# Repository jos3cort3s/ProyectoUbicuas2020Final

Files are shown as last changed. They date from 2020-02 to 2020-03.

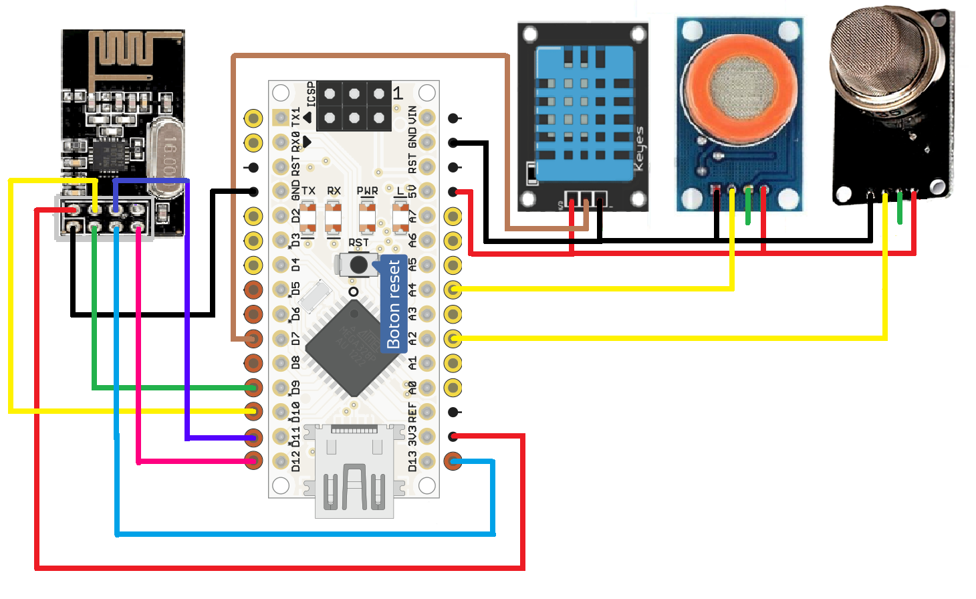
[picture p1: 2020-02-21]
ProyectoArduino/Imagenes/ConectionExternalModule.png

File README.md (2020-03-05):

# Proyecto Plataformas Ubicuas 2020

## Resumen 📋

El proyecto CoPPm es la integración de diversos sistemas informáticos y  herramientas hardware bajo costos, que permita el aprendizaje y la interacción con diversos sistemas telemáticos, sistemas IoT, además el  modelado de piezas en 3D para la creación de prototipos que permitan dar  la solución a los problemas cotidianos y den valor agregado a  proyectos educativos.
Este proyecto reúne el uso de sensores y controladores arduino, para la creación de dos módulos que permitan sensar y notificar  a los usuario que grado grado de contaminación existe en su entorno, esto permite que los usuarios puedan tomar acciones preventivas que ayuden a minimizar problemas de salud. El sistema se complementa con una App Móvil Android y un servicio en la Nube que da al usuario herramientas para el seguimiento de la calidad del aire en sus rutinas diarias y recomendaciones de sus recorridos y hábitos de manejo que minimice la interacción con puntos críticos. El sistema funciona como una red de sensores,  en donde cada usuario se comporta como nodo, brindando un mayor espectro de las condiciones reales de contaminación en una ciudad.
En las Carpetas puedes encontrar toda la documentación,  códigos, librerías, y modelos 3d que fueron utilizados en este proyecto. 

## Introducción 🚀

Se espera que hacia 2050 la población mundial pase de 7 mil millones de personas a más de 9 mil millones y se proyecta que la economía mundial crezca casi cuatro veces, con una creciente demanda de energía y de recursos naturales. Se proyecta que hacia 2050 casi 70% de la población mundial será urbana, lo que aumentará los desafíos respecto a la contaminación atmosférica, la congestión del transporte y la gestión de la basura. Bajo este escenario la contaminación del aire se convertirá en la principal causa ambiental de mortalidad prematura en el mundo, para el 2050 el número de muertes prematuras derivadas de la exposición a partículas suspendidas aumentará más del doble y alcanzará 3.6 millones cada año.
En América Latina y el Caribe (LAC por sus siglas en inglés), por lo menos 100 millones de personas están expuestas a niveles de contaminación del aire por encima de los recomendados por la Organización Mundial de la Salud (OMS) (Cifuentes, 2005). Los grupos más vulnerables a los efectos dañinos de una mala calidad del aire incluyen a niños, adultos mayores, personas con previos problemas de salud y población de bajos estratos socioeconómicos (Joanne Green, 2013). 
En Colombia un informe  realizado por el Departamento Nacional de Planeación (DNP), concluye que la contaminación del aire mata cada año en promedio a 8.000 personas mayores de 44 años, de este total, 668 están relacionadas con cáncer de pulmón y 7.362 con enfermedades cardiopulmonares, enfermedades que seguirán en aumento el los próximos años. 
En el caso de Bogotá, la Cámara de Comercio informó que la capital solo cuenta con 13 estaciones de monitoreo fijo y una móvil las cuales resultan insuficientes para registrar la calidad del aire, las cuales presentan datos parciales, que no interpretan a cabalidad las condiciones reales de contaminación en lugares puntuales de la ciudad (Getty, 2019).

### Por qué 📌
Porque tu salud y la de tus eres queridos es el mayor privilegio que puedes tener.

### Cómo ✒️
Nuestros productos brindan la posibilidad de que las personas tomen las mejores decisiones en el cuidado de su salud,  basadas en la informacion presisa y oportuna.

### Qué 📄
Ofrecemos un producto para Vehiculos y servicios en la nube que permitan el monitoreo y alerta de las condiciones de contaminates en el aire a nivel del suelo en tiempo real, seguimiento de los puntos criticos de contaminacion en el aire en tus recorridos cotidianos.

## Video 📢
Para  observar la puesta en funcionamiento del prototipo final, se a creado un vídeo en donde se visualizan los principales detalles del sistema. Cualquier observación, retroalimentación o duda la puedes dejar en los comentarios del vídeo, si te fue de utilidad déjanos tu like.

https://www.youtube.com/watch?v=Scrf4-CmwAs

## Autores ✒️

* **Jose Luis Cortes Carvajal** - *Trabajo Inicial* - [Profil Link](https://github.com/jos3cort3s)

## Expresiones de Gratitud 🎁

* Comenta a otros sobre este proyecto 📢 
* Da las gracias públicamente 🤓.

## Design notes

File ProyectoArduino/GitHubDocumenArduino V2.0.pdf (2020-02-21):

Documentación Hardware

Sistema de Monitoreo Externo

Componentes

- Arduino NANO

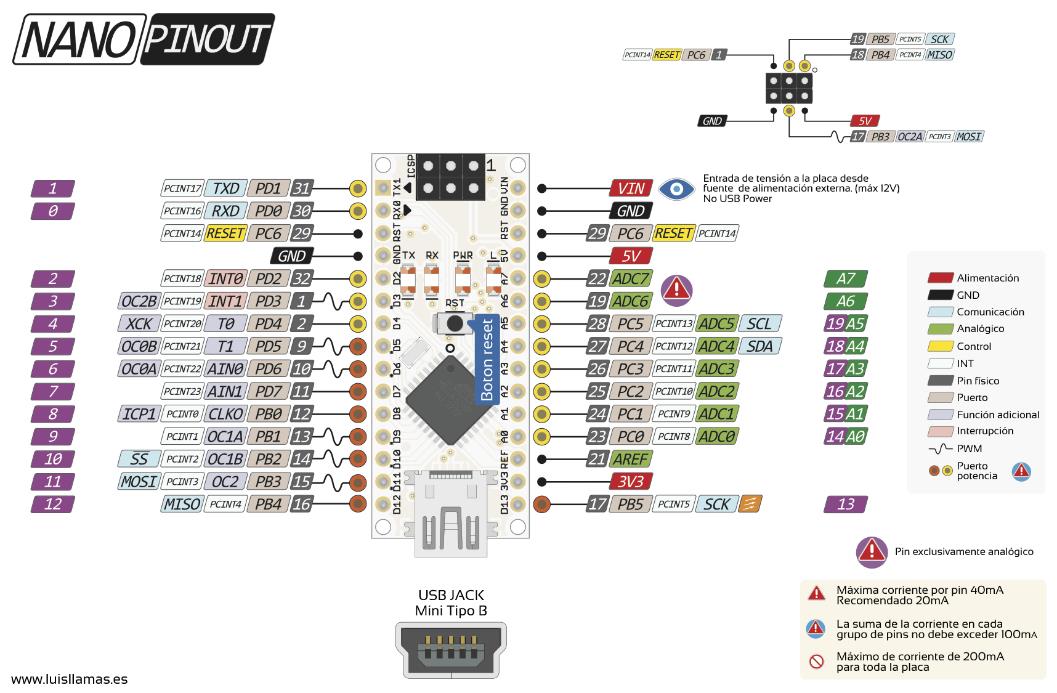
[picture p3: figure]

- MQ7 Air Co2 Sensor
- MQ135 Air Quality Sensor

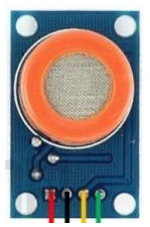
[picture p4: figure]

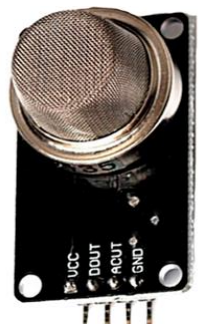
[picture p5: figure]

- DTH-11 Sensor(Temperature-Humidity)
- NFR2410 2.4Ghz Module TX

Conecxión

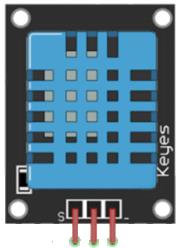
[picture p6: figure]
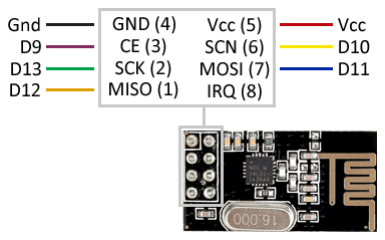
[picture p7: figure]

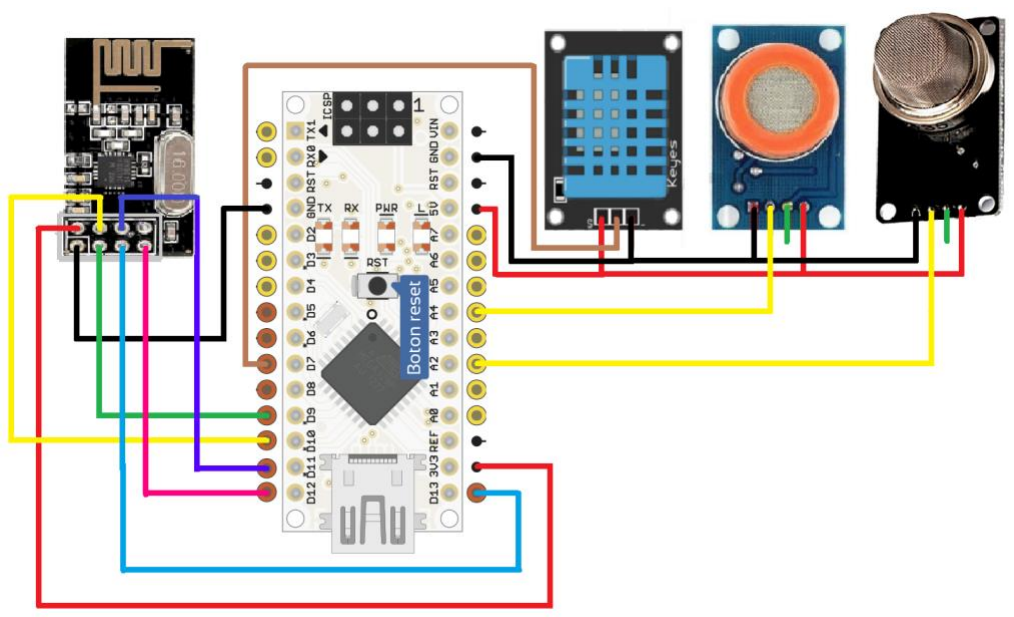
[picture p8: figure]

Sistema de alerta Interno

Componentes
- Arduino NANO
- NFR2410 2.4Ghz Module RX
- Led Indicator
- BLE HC-05 Wireless Module

Conexion

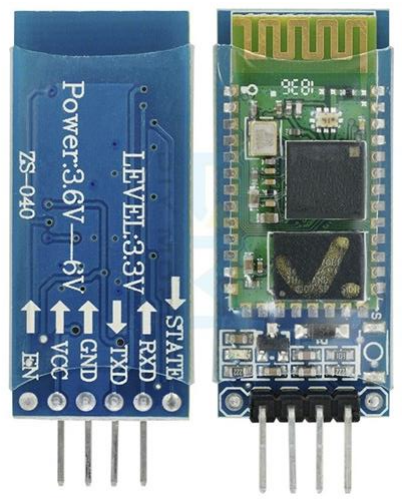
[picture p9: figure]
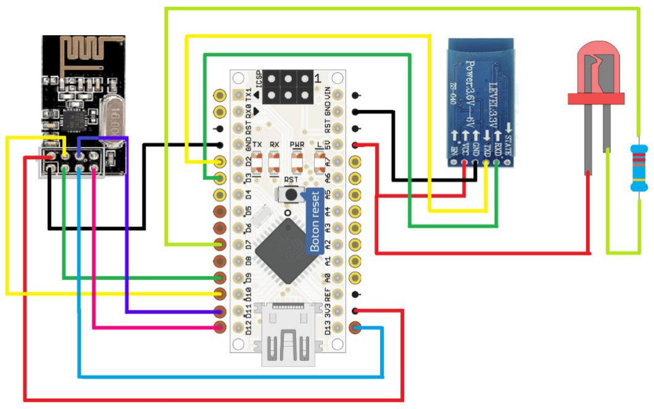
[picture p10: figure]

Docuemntacion Software

Sistema de Monitoreo Externo

Documentation

El dispositivo número 1, es un dispositivo que tiene como propósito la medición de la calidad del aire en ambientes citadinos, por lo cual está pensado para ser ubicado en un lugar exterior, en donde los sensores tengan contacto directo con el aire circundante. Partiendo de que existe una conexión física entre los sensores y el módulo arduino, es el momento de iniciar el desarrollo del código de proyecto, Para este módulo se tiene, un fragmento de código que permite la lectura del sensor dht11, un fragmento de código para la configuración y lectura de los sensores MQ (mq7 y mq135) y por último el fragmento de código para controlar la comunicación RF (Radio Frecuencia) entre los módulo NFR24L01.

- Sensor Dht11

Las puesta en marcha de este sensor es bastante sencillo, existen diferentes librería que integran funciones y que te permitieran una lectura fácil y correcta del sensor. Para este proyecto se ha utilizado la libreria DX11.zip que integra comandos muy facies de utilizar, y ejemplos de gran ayuda para implementar en arduino IDE, lo único que debes hacer es descargar la librería e importala.

Si deseas un ejemplo más completo de la puesta en funcionamiento de este sensor puedes visitar el link: https://www.prometec.net/sensores-dht11/

- Sensor NFR24L01

El NRF24L01 es un chip de comunicación que integra un transceptor RF a una frecuencia entre 2.4GHz a 2.5GHz, banda libre para uso gratuito. La velocidad de transmisión es configurable entre 250 Kbps, 1Mbps, y 2 Mbps. La librería utilizada en el proyecto para el control de este módulo es nRF24/RF24, (https://github.com/nRF24/RF24) la cual presenta funciones y ejemplos que pueden ser de ayuda en el desarrollo de futuros proyectos.

Si deseas mayor informacion del funcionamiento de este modulo puedes visitar la pagina https://www.luisllamas.es/comunicacion-inalambrica-a-2-4ghz-con-arduino-y-nrf24l01/

- Sensores MQ

Los sensores MQ corresponden a una gran variedad de dispositivos para la medición de gases disueltos en el aire, estos sensores son electroquímicos y varían su resistencia cuando se exponen a determinados gases, internamente posee un calentador que aumenta la temperatura interna lo que le permite reaccionar a los gases.

Existen diversos sensores MQ, cada uno con características que lo hacen ideales para la medición de uno o varios gases en particular. En este proyecto se hará uso de los sensores MQ7 para la medición de CO “Monóxido de carbono” y M135 para las mediciones de NH4 “Amonio”. Este tipo de sensores son fáciles de poner en funcionamiento, la mayoría cuentan con una salida digital booleana (1 - 0), o una salida analogica (0v – 5v). El mayor reto y paso importante para las puesta en funcionamiento de este tipo de sensores MQ es la calibracion, proceso con el cual se establece una función que permite que el sensor realice las mediciones con precisión de las condiciones ambientales.

Si deseas una mayor información de toda la gama de sensores MQ, ademas de la documentacion oficial revisa el link: https://playground.arduino.cc/Main/MQGasSensors/

Calibración

El proceso de calibración de este tipo de sensores se divide en 3 pasos:

Paso 1

Leemos los pines analogicos de la arduinoNano, con lo cual obtenemos una valor en voltios que es la respuesta del sensor MQ. Los microcontroladores utilizados por arduino en sus módulos, tienen la incapacidad de interpretar una señal puramente analogica como lo es un voltaje, por lo cual usan un conversor Análogo – Digital interno en sus pines analogicos con una resolucion de 10 bits, con lo cual un el valor de 0 voltios analógico puede ser expresado en digital como 0000000000 (0) y un valor de 5V analógico es expresado en digital como 1111111111 (1023). Por lo tanto todo valor analógico intermedio al final es expresado como un valor digital entre 0 y 1023.

En el codigo primero realizamo la lectura del pin analogico donde conectamos el sensor MQ, con esto se obtiene un valor entre 0 y 1023.

adc_MQ = analogRead(analogPin)

Por medio de una regla de tres simple convertimos el valor digital obtenido en un valor de voltaje entre 0v y 5v

readVolt = adc_MQ * ( powerVolt / 1023.0)

Equation 1

Si implementas esto en codigo vas a obtener una lectura digital entre 0 y 1023, y su respectiva conversión a voltios entre 0v y 5v, pero aunque podríamos interpretar esta señal como la cantidad de particulas por millon (ppm) de un determinado gas en el ambiente las cosas no son tan fáciles. La mayoría de sensores de este tipo son sensibles a múltiples gases, así que cualquier gas podría generar cambios de valor en el sensor, y no específicamente el gas que es de tu interés medir, esto genera lecturas erróneas. Por otro lado el comportamiento de los sensores MQ entre la lectura analógica y el valor real no es del todo lineal, por lo cual se debe estimar la curva de comportamiento que nos ofrecen en el dataSheet (paso 2)

Paso 2

En este paso se realiza la estimación de la ecuación para la curva de comportamiento del sensor para un gas en particular. Como se aprecia en la gráfica 1, imagen que se extrajo del datasheet para el sensor MQ 07. Como se aprecia este sensor se comporta diferente ante la presencia de diversos gases como co, h2, lpg, ch4, alcohol y aire.

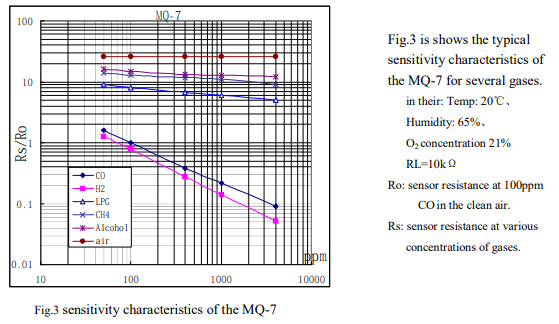
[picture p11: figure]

Grafica 1

Para este caso en particular el gas que nos interesa es el monóxido de carbono, por lo cual utilizamos la línea correspondiente para este gas (linea azul con rombos). De forma manual obtenemos los puntos, los graficamos y por medio de la herramienta excel se obtiene la línea de tendencia que más se aproxime a los datos suministrados, al obtener la linea de tendencia también observamos la ecuación correspondiente.

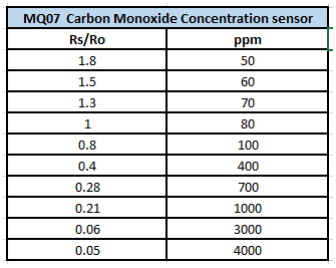
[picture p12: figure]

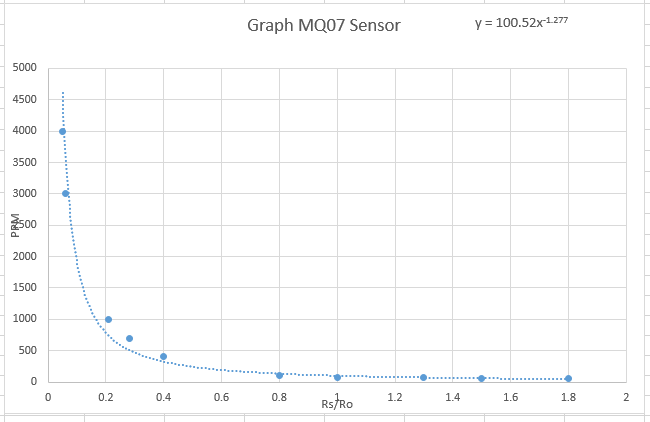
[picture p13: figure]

Grafica 2

y = 100.52 x

−1.277

Equation 2

Reemplazando y = ppm y x = Rs/Ro se obtiene

ppm = 100.52 (

Rs
Ro)

−1.277

En donde ppm es la cantidad de particulas por millon de monóxido de carbono disueltas en el aire, Ro es la resistencia del sensor a un concentración de 100 ppm de monóxido de carbono y Rs es la resistencia del sensor a varias concentraciones del gas. Esta ecuación presenta 3 incognitas ppm de monóxido de carbono, Rs y Ro.

Para calcular el valor de Rs despejamos la ecuación del divisor de voltaje que forma el sensor con la resistencia de carga RL que se especifica en el datasheet, para el caso de este sensor RL = 10kΩ.

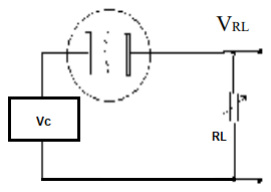
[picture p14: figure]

VRL = Vc(

RL
Rs + RL

)

Equation 3

Despejamos Rs de la ecuación 3 se obtiene

Rs = RL (

Vc

VRL

− 1 )

donde Vc = 5v, | RL = 10KΩ, | VRL = readVolt

Recordar que el voltaje en RL es el voltaje de salida del sensor, que a su vez es el voltaje que se obtenía con la ecuación 1, cuando leiamos la entrada analogica de la Arduino. Al reemplazar en la formula queda como la ecuación 4. Tener en cuenta que el valor de Rs está variando constantemente y esto depende de la concentracion de monoxido en donde se encuentre el sensor

Rs = RL (

| Vc
readVolt − 1 )

Rs = 10KΩ (

5v
readVolt − 1 )

Equation 4

Paso 3

A diferencia de Rs, Ro es un valor constante que representa la resistencia del sensor a una única concentración de 100ppm aire limpio, por lo cual para calcular este valor hacemos uso del gráfico 2. En este gráfico se aprecia que a concentraciones muy altas de CO la variación en el valor de Rs/Ro son mínimas, a diferencia que a concentraciones bajas de CO en donde las variaciones de Rs/Ro son significativas. Con el fin de minimizar los errores lo mejor sería elegir Rs/Ro para concentraciones altas de CO, en la gráfica observamos que la mayor concentración es de 4000 ppm de CO y que a esta concentración el valor de Rs/Ro = 0.05 aprox.

Entonces asumiendo que el sensor se satura con 4000ppm al cual según la gráfica le corresponde un Rs/Ro de 0.05. Para estar en este punto de saturacion generamos un ambiente con bastante CO y medimos con el sensor, al realizar esta medicion se obtiene un voltaje de 4.02 v, que al reemplazar en la ecuacion 4 se tiene un valor de Rs=2437.81Ω.

Rs = 10KΩ (

5v
readVolt − 1 )

Rs = 10KΩ (

5v
4.37v

− 1 )

Rs = 1441.64 Ω

Se sabe que Rs / Ro sera igual a 0.05 a concentraciones muy altas de CO por lo cual

Rs/Ro = 0.05

Despejamos Ro y reemplazamos Rs

Ro = Rs/0.05

Ro = 1441.64 / 0.05

Ro = 28832

Con Ro calculado, ya tenemos una solución de la ecuación y con esto podemos obtener los valores aproximados de concentración de CO, .

ppm = 100.52 (

Rs
Ro)

−1.277

ppm = 100.52 (

Rs
28832)

−1.277

Para el módulo MQ135 se realiza exactamente el mismo proceso, entre los dos sensores existen cambios significativos al calcular la línea de tendencia, y esto es normal ya que cada sensor de la serie MQ presenta un comportamiento en particular que debe ser tenido en cuenta, esto se aprecia en el dataSheet. Es importante decir que existen en la web diferentes proceso de calibracion para estos sensores, este proyecto tomo como referenica la informacion y procedimientos que se siguieron en el link: https://naylampmechatronics.com/blog/42_Tutorial-sensores-de-gas-MQ2-MQ3-MQ7-y-MQ13.html

Código completo
Como se aprecia en este código he utilizado los diferentes ejemplos de código individuales para el para el control de los sensores y los he combinado en uno solo. Además de la creación de una funcion que contiene código que se reutiliza tanto para el sensor MQ07 como para el MQ135.

#include <DHT11.h> // Incluye librería para manejo DHT

#include <SPI.h>

#include <nRF24L01.h> //Incluye libreria para manejo tranceptor #include <RF24.h>

#include <SoftwareSerial.h>

int pin=7;
DHT11 dht11(pin);

const int pinCE = 9;
const int pinCSN = 10;
RF24 radio(pinCE, pinCSN);

// Single radio pipe address for the 2 nodes to communicate. const uint64_t connect1 = 0xE8E8F0F0E1LL;
float data[4];

float temp, hum;
float monOxide, nh4, Rs;

void setup() {
Serial.begin(9600);

radio.begin();
radio.openWritingPipe(connect1);

}

void loop() {

//------- Llenamos el arreglo con los datos de los dos sensores MQ y DHT -----------------

dht11.read(hum, temp); // Hacemos uso del método read para leer y asignar valor a las variables hum y temp

Rs = functReadMQSensor(A4, 5, 10000);
monOxide = 100.52 * pow(Rs/5463, -1.277); // Esta ecuación se obtiene por medio de una regresión lineal, exponencial según sea el caso, //para el sensor Mq7 es esta, pero varía dependiendo del sensor (revisar DataSheet del sensor) //calculamos la concentración de monóxido de carbono con la ecuación obtenida.

Rs = functReadMQSensor(A2, 5, 20000);
nh4 = (30.593 * pow(Rs/5463, 2)) - (167.14 * (Rs/5463)) + 231.55; // Esta ecuación se obtiene por medio de una regresión lineal, exponencial según sea el caso, //para el sensor Mq135 es esta, pero varía dependiendo del sensor (revisar DataSheet del sensor) //calculamos la concentración de nh4 con la ecuación obtenida.

data[0] = monOxide;
data[1] = nh4;
data[2] = temp;
data[3] = hum;

radio.write(data, sizeof data);
delay(5000);
}
float functReadMQSensor(int analogPin, float powerVolt, float rL){ // analogPin pin conexion sensor, inVoltage voltaje de alimentación Sensor (5v o 3.3v)
int adc_MQ = analogRead(analogPin); //Leemos el puerto analogico para determinar la salida analógica del sensor MQ
float readVolt = adc_MQ * ( powerVolt / 1023.0); //Convertimos la lectura en un valor de voltaje
float rS = rL *((5-readVolt)/ readVolt); //Ecuación del divisor de voltaje, formada por el sensor y resistencia rL, permite calcular rS
return rS; | // para el sensor MQ7 rL = 10K, para MQ135 rL = 20K (Segun datasheet)
}

Sistema de Alerta Interno

Documentation
El dispositivo número 2 funciona como interfaz que comunica al usuario en tiempo real y por medio de una luz intermitente, cuando los niveles de CO o HN4 están por encima de los parámetros especificados ( > 50 ppm) lo que podrían generar desde molestias respiratorias hasta daños severos a la salud. El dispositivo está pensado para ser ubicado en espacios interiores donde el usuario los ubique fácilmente con la vista, este dispositivo cuenta con conexión bluetooth para poder ser vinculado a la aplicación móvil android y de esta forma generar un seguimiento de los niveles de contaminantes en el aire de las vías transitadas.
- Sensor NFR24L01

Este dispositivo hace uso de mismo modulo NRF24L01 pero esta vez configurado como receptor, La librería utilizada en el proyecto para el control de este módulo es nRF24/RF24. (https://github.com/nRF24/RF24)

Si deseas mayor informacion del funcionamiento de este modulo puedes visitar la pagina https://www.luisllamas.es/comunicacion-inalambrica-a-2-4ghz-con-arduino-y-nrf24l01/

- Modulo BLE HC-08 Wireless

El módulo Bluetooth HC-08 es parte de la nueva generación de dispositivos para la transmisión de datos usando el protocolo Bluetooth Low Energy “BLE” o Bluetooth V4.0, este dispositivo funciona con una frecuencia de trabajo de 2.4Ghz y un alcance máximo de 100m a línea de vista. Esta pensados para brindar la posibilidad de comunicación a tus proyectos con dispositivos que implementen esta tecnología, brindando un bajo consumo de energía y costos de operación considerablemente reducidos.

Para la puesta en funcionamiento de este sensor el primer paso es la configuracion del modulo,
características como | Modo: Maestro – Esclavo, Nombre: HC-05, Contraseña: 1234, Velocidad (baud
rate): 9600 pueden ser modificadas, acción que se realiza por medio de | comando AT. Para este proceso
debemos conectar el módulo BLE HC-08 a la tarjeta arduino, en este caso se ha seleccionado los pines 2 y 3 como Rx y Tx respectivamente, pero pueden varias según tus preferencias.

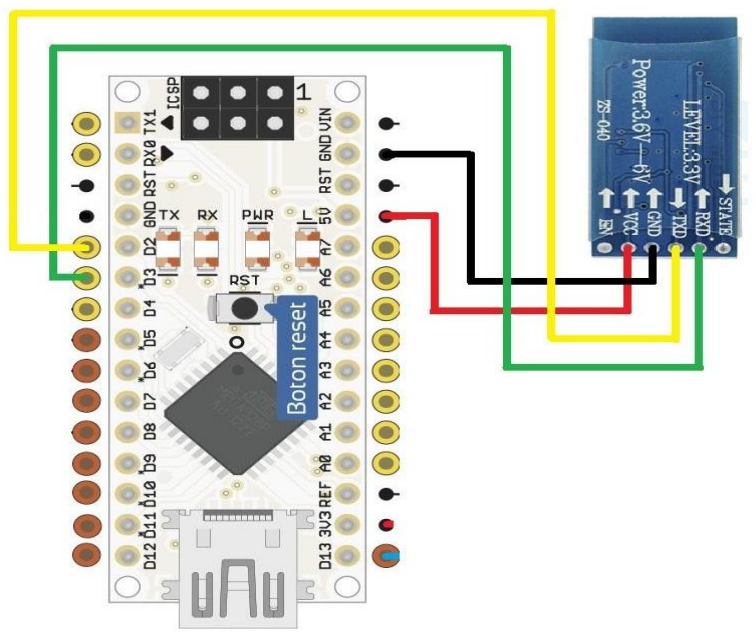
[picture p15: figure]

Codigo configuracion modulo BLE por comandos AT

#include <SoftwareSerial.h> SoftwareSerial SerialBt(2,3);

void setup()
{
SerialBt.begin(115200);
Serial.begin(115200);
Serial.println("Enter AT commands:");

}
void loop()
{
if (SerialBt.available()) { Serial.write(SerialBt.read()); }
if (Serial.available()) {
SerialBt.write(Serial.read()); }
}

Nota: Es muy importante que la velocidad en baudios configurada en el módulo HC-08 sea igual a la velocidad con la que configuras tu comunicación serial en la Arduino al momento de programar.

Lista de comandos AT

AT — check operability;

AT+HELP — output all commands;

AT+DEFAULT — reset factory settings;

AT+RESET — soft reset;

AT+ROLE — output current mode;

AT+ROLE0 — set slave mode;

AT+NAME — output module name;

AT+NAMESimon — set module name as Simon;

AT+PIN — output PIN code (password) for pairing;

AT+PIN123456 —set PIN code as 123456;

AT+UUID — output service UUID;

AT+UUID0xFFE0 — set service UUID as 0xFFE0;

AT+CHAR — output characteristic UUD;

AT+CHAR0xFFE1 — set characteristic UUID as 0xFFE1.

Código completo

#include <SPI.h>

#include <nRF24L01.h>

#include <RF24.h>

#include <SoftwareSerial.h>

const int pinCE = 9;
const int pinCSN = 10;
RF24 radio(pinCE, pinCSN);

SoftwareSerial SerialBLE(2,3); //puerto de comunicación BLE

const int ledPIN = 7; // pin de salida del LED indicador

// Single radio pipe address for the 2 nodes to communicate. const uint64_t connect1 = 0xE8E8F0F0E1LL;

float data[4]; // Arreglo de datos que son recibidos del emisor uint8_t dataBLE[20]; // Arreglo de datos que serán enviados al Móvil

void setup()
{
radio.begin();
Serial.begin(115200);
SerialBLE.begin(115200); /// Velocidad de los Baudios para la comunicación BLE radio.openReadingPipe(1, connect1);
radio.startListening();
pinMode(ledPIN , OUTPUT); //definir pin como salida
}

void loop()
{
if (radio.available())
{
radio.read(data, sizeof data); // Recibo los datos del modulo Emisor y los alaceno el el arreglo "data"

if(data[0]>50 || data[1]>50 ){// en caso de que las variables CO o NH4 sean elevadas se enciende el LED digitalWrite(ledPIN , HIGH); // poner el Pin en HIGH
//delay(1000); // esperar un segundo
}
else{
digitalWrite(ledPIN , LOW); // poner el Pin en LOW
//delay(1000); | // esperar un segundo
}

for(int i=0; i<20; i=i+4){
dataBLE[i] = data[0]; // colocamos el valor de Co2 que se encuentra en data[0], y lo almacenamos en dataBLE dataBLE[i+1] = data[1];// lo mismo con este y el resto
dataBLE[i+2] = data[2];
dataBLE[i+3] = data[3];
}

Serial.print("Co2 = " );
Serial.print(data[0]);
Serial.print("NH4 = " );
Serial.print(data[1]);
Serial.print("--Temp = " ); Serial.print(data[2]);
Serial.print("--Hum = " );
Serial.println(data[3]);

SerialBLE.write(dataBLE, 20); //Envía el arreglo al movil }
delay(1000);
}

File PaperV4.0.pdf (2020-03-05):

# Plataforma para la medición de calidad del aire basado en IoT para sistemas de transporte

urbano.

Air quality measurement platform based on IoT for urban transport system.

Autor¹ CORTES, Jose Luis

Autor² RAMIREZ, Gustavo

Resumen

El impacto de la calidad del aire en la salud y la comodidad de las personas es un tema de interés para ingenieros e investigadores alrededor del mundo, una de las poblaciones más vulnerables son las personas que pasan un numero considerables de horas expuestas a contaminantes en el aire, especialmente los ancianos y niños. Este documento presenta el desarrollo de un sistema de medición de calidad de aire a nivel del suelo de bajo costo, basado en IoT para su uso en vehículos de transporte privado de pasajeros que se desplacen en zonas urbanas, este gadget vehicular posee la capacidad de medir Co, Co2, PM2.5 temperatura ambiente, humedad relativa, y notificar por medio de luz intermitente cuando sé esta atravesando por zonas con niveles de contaminación en el aire por encima de los parametros establecidos.

Palabras clave
IoT, Calida del Aire, Android, Bluetooth Low Energy, Middleware.

Abstract

The impact of air quality on people's health and comfort is a topic of interest to engineers and researchers around the world. One of the most vulnerable populations are people who spend a considerable number of hours exposed to air pollutants, especially the elderly and children. This document presents the development of a low-cost, IoT-based, ground level air quality measurement system for use in private passenger transport vehicles moving in urban areas. This vehicle gadget has the ability to measure Co, Co2, PM2.5 ambient temperature, relative humidity, and notify by flashing light when it is passing through areas with air pollution levels above established parameters.

key words
IoT, Air quality, Android, Bluetooth Low Energy, Middleware.

1
Estudiante. Universidad del Cauca. joseluiscortes@unicauca.edu.co 2 Docente. Universidad del Cauca. gramirez@unicauca.edu.co

## 1. Introducción

La calidad del aire de las ciudades se está convirtiendo en una gran preocupación para las personas que las habitan y sus responsables políticos. Recientemente algunos países de la Unión Europa y América del Norte han incrementado sus esfuerzos con el fin de reducir las emisiones de varios contaminantes atmosféricos (Air, 2018) como el monóxido de carbono (CO), el dióxido de azufre (SO2), el material particulado (PM) y algunos otros compuestos orgánicos que se consideran como una grave amenaza para la salud pública.

En los últimos años el crecimiento demográfico de las ciudades, a generado un aumento del parque automotor, transportes públicos y privados que busca satisfacer las necesidades de movilidad dentro de las ciudades. Con la llegada de nuevos vehículos a las vías, el incremento de contaminantes en el aire y la disminución de la movilidad es un problema que afecta a las grandes urbes alrededor del mundo. Según estudios de movilidad vehicular (INRIX, 2018) algunas de las ciudades que presentan el mayor índice en problemas de congestión vehicular y en donde las personas pierden mayor tiempo detenidos en el tráfico son Bogotá, Moscú, Estambul, y ciudad de México. En relación con el tiempo que los vehículos se encuentran detenidos en el tráfico un estudio realizado por (P. Kumar, 2016) comprobó que los contaminantes al interior de un vehículo aumentan hasta un 40 por ciento, cuando se encuentra en un atasco o cuando el semáforo está en rojo.

Aunque la mayoría de las ciudades actualmente cuentan son sistemas de análisis de calidad de aire automáticos, de gran precisión, su complejidad y elevados costos hacen imposible una instalación a gran escala. Por lo cual estos sistemas son instalados solo en lugares de vigilancia determinados y fijos, lo que dificulta la recolección de datos que permitan predecir la situación general de la contaminación en las vías a nivel del suelo. Para superar los defectos del sistema de vigilancia y los métodos de detección tradicionales y reducir el costo de las pruebas, en este documento se propone un método que combina la tecnología de la IoT para el monitoreo del medio ambiente, que junto con los equipos de monitoreo tradicional formarán una red de sensores que proporcione apoyo de datos para futuras predicciones.

De acuerdo con la arquitectura de IoT, el sistema se compone principalmente de 3 capas, capa de percepción, capa de red y capa de aplicación. La arquitectura integral del sistema se muestra en la figura 1.

1.1. Capa de percepcion.

La capa de percepción incluye principalmente el módulo en donde se ubican los sensores de medición y que se encuentran en contacto directo con el aire circundante del punto de medición. En el sistema se realizó con un presupuesto aproximado de 100.000 pesos Colombiano y permite la medición de variables como el monóxido de Carbono Co, dióxido

Plataforma para la medición de calidad del aire basado en IoT para sistemas de transporte urbano.

3

de Carbono Co2, material particulado PM2.5 , temperatura ambiente y humedad relativa, con un consumo promedio aproximado de 60 mA.

De acuerdo con las metodologia propuesta, el sistema estara montado en vehiculos de transporte colectivo que recorren rutas específicas de la ciudad. El esquema de monitoreo se optimiza teniendo en cuenta la influencia del clima de la región y la posición de la ubicación del sistema de percepción. En (Cortes, 2020) se puede encontrar el repositorio con toda la documentación técnica, hardware utilizado y software desarrollado para este proyecto.

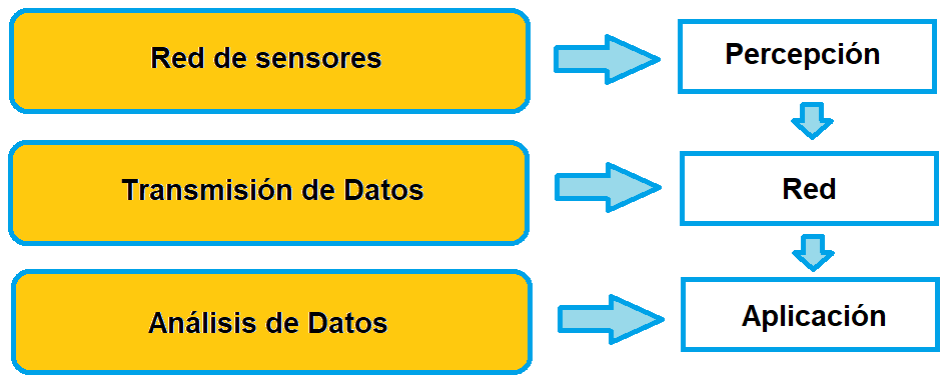
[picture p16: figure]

Figure

1. Arquitectura del sistema.

### 1.2. Capa de red

La capa de red permite transmitir los datos ambientales de la calidad de aire percibidos por los sensores, a un servidor central que unifica la información y despliegan los datos en tiempo real. El sistema de red está constituido por una comunicación RF entre el módulo de sensores y el módulo de alerta, utilizan el protocolos de comunicación SPI. El módulo de alerta evalúa los datos y los compara con parámetros establecidos, si lo niveles de contaminantes en el aire son elevados el módulo de alerta genera una señal de luz intermitente, este módulo se comunica con el SmartPhone por medio de una comunicación Bluetooth Low Energy BLE y las capas de su pila de protocolos. EL Controller que es el dispositivo físico que permite transmitir y recibir señales de radio e interpretarlas como paquetes con información y el Host es el software que administra la comunicación entre dos o más dispositivos (Akhayad A, 2016). En la Figura 2 se aprecia las capas de la pila del protocolo para Bluetooth Low Energy.

Estos datos son enviados al servidor por medio de la red móvil disponible en el smartPhone, este proceso implementa una estructura de datos JSON , en este caso se hace uso de MiddleWare UBIDOTS que presta servicios en la nube que permiten almacenar datos y visualizarlos en tiempo real a través de su sitio web. El sistema de transmisión está basado en una arquitectura orientada a los servicios.

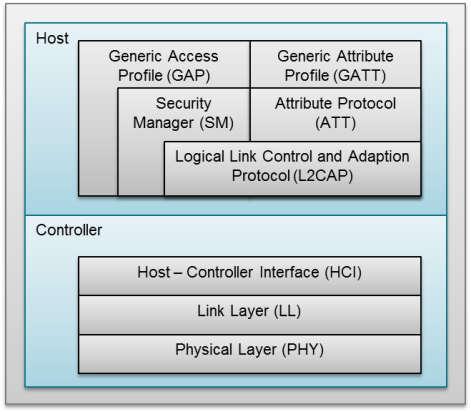
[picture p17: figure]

Figure 2. Pila de protocolos para BLE. Fuente (Smartlighting, 2019)

### 1.3. Capa de aplicación

La capa de aplicación está destinada al procesamiento y análisis de los datos recolectados, datos de contaminantes en el aire, posición, humedad, temperatura entre otras condiciones meteorológicas se evalúan para predecir con menor error el comportamiento de estas variables en el futuro. La plataforma Ubidots permite la introduccion de tecnologias de análisis de datos

## 2. Metodología

El sistema de monitoreo de la calidad del aire basado en sensores MQ y DSM, permite la medición de contaminantes ambiental, posee un buena precisión y un bajo costo. Las variables que se pretenden medir son el monóxido de carbono CO, dióxido de carbono CO2, material particulado PM2.5, humedad relativa y temperatura ambiente. Este módulo esta compuesto por sensores MQ07, MQ135, DSM501, DTH22, arduino nano y sistema de comunicación RF, está diseñado para ser ubicado en la parte exterior de los vehículos, en donde los sensores tengan contacto directo con el aire circundante.

El lugar seleccionado para realizar las mediciones es la ciudad de Popayán – Colombia, la cual es una ciudad intermedia con un área de 483.11 Km2, en los últimos censos del departamento administrativo nacional de estadísticas DANE se estima que posee una población provicional de 325.477 habitantes (Estadistica, 2018), cuenta con un promedio de 60.000 vehículos en circulación entre automóviles y motocicletas.

El procedimiento establecido para la recolección de los datos consiste en el montaje del sistema de monitoreo en un vehículo de transporte público colectivo, que se encuentre en

Plataforma para la medición de calidad del aire basado en IoT para sistemas de transporte urbano.

5

constante circulación alrededor de la ciudad y que esté en funcionamiento un mínimo de 15 horas al dia. La recolección de los datos se realizará en un periodo 30 dias. Los datos serán comparados con los registros oficiales generados por las autoridades ambientales de la ciudad.

## 3. Conclusiones

Este trabajo presentó un sistema modular para el monitoreo de la calidad del aire en sistemas de transporte urbano, compuesto por una serie de red de sensores inalámbricos, puertas de enlace smartphone y sistema de servicios IoT en la nube. El sistema permite la monitorización de dos tipos de gases; monoxido de carbono y dióxido de carbono, además medición de material particulado PM2.5, temperatura ambiente y humedad relativa. Debido a que el sensor está ubicado en un plataforma en movimiento, genera su ubicación por GPS de los diferentes ubicaciones recorrida.

La fiabilidad de los sistemas de comunicación tiene sus limitantes por lo cual se implementó una base de datos en el smartphone, que almacena la información localmente en caso de fallo por desconexión de Internet.

La modularidad del sistema permite la escalabilidad y, por lo tanto, el sistema puede integrar un gran número de nodos, lo que permite una adaptación a diversas aplicaciones.

## Referencias bibliográficas

Air, O. N. (2018). The U.S. Environmental Protection Agency (EPA). Annual Air Trends Report, 2017.

Akhayad A, G. J. (2016). Bluetooth 4.0 Low Energy: Análisis de las prestaciones.

Cortes, | J. | (02 | de | 2020). | Repositorio | GitHub. | Obtenido | de
https://github.com/jos3cort3s/ProyectoUbicuas2020Final (https://github.com/jos3cort3s/UbicuasProject2020)

Estadistica, D. A. (2018). Censo nacional de población y vivienda 2018. Censo Nacional.

INRIX. (2018). Global Traffic Scorecard.

P. Kumar, A. G. (2016). Concentration dynamics of coarse and fine particulate matter at and around signalised traffic intersections. Universidad de Surrey, en Reino Unido.

Smartlighting. (Mayo de 2019). Bluetooth Low Energy – Introducción a la tecnología.
Obtenido | de | https://smart-lighting.es/bluetooth-low-energy-introduccion-la-
tecnologia/ (https://smart-lighting.es/bluetooth-low-energy-introduccion-la-tecnologia/)

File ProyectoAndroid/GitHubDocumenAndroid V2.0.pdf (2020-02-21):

Documentación Software Aplicacion para Android

Permisos

Para la impelementacion Bluetooth Low Energy “BLE” en dispositivos Android es necesario el uso de permisos dentro el archivo manifest.xml. Para que la aplicacion tengan un funcionamiento optimo los permisos que se deben implementar son:

BluetoothLeService.java

Esta clase es proporcionada por Android para el manejo de BLE, con mínimas modificaciones puede ser implementada y permite realizar todas las funciones de CALLBACK de BLE. Para poder leer es necesario llamar dentro de la función readCharacteristic(mreadcharacteristic) e ingresar la referencia en la función.

Estas funciones en Android funcionan de manera asíncrona, de tal manera que no siguen un orden secuencial, las funciones de nombre onXXXX son llamadas por defecto sin la necesidad de ser invocadas, en el caso anterior al llamar a readCharacteristic (), empieza automáticamente a correr la función onReadCharacteristic ().

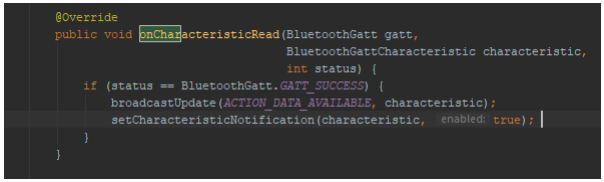
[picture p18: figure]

Esta funcion utilizan “broadcastUpdate()” para modificar el TextView , en esta zona se utiliza el setCharacteristicNotification(characteristic, true) , donde se envía la referencia de la característica y se activa, la opción de notificación en el descriptor de la característica del servicio, la opción de notificación debe ser previamente programada en el dispositivo central, y dentro de nuestro dispositivo periférico se podrá activar, de esta forma se logra cambiar los resultados, de la característica automáticamente sin necesidad de presionar el botón de lectura constantemente.

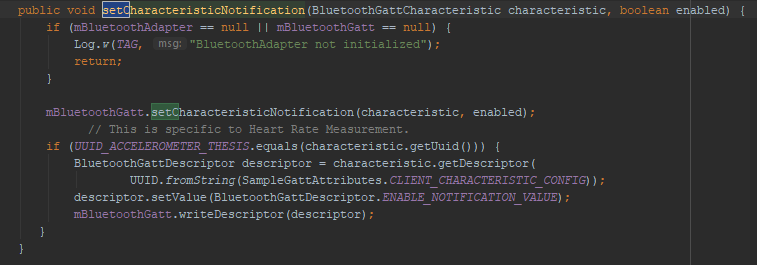
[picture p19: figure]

Los datos recibidos por el bluetooth, vienen en una cadena de datos, los cuales tienen que ser descifrados directamente en el código, donde se podrán recibir hasta 20 bytes de comunicación, mientras que en el advertising se pueden utilizar hasta 31 bytes y con el uso de SCAN RESPONSE. Para poder descifrar los datos se utiliza un método genérico ofrecido por Android con el código.

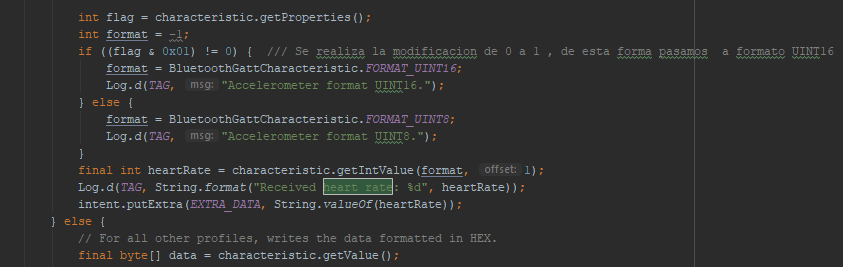
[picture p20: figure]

DeviceControlActivity.java

En esta clase se crean todas las funciones que se conectan directamente con los botones del layout, esta clase java hereda de activity, contiene las clases override onCreate (), onResume (), onPause (), onDestroy (), onCreateOptionsMenu (), onOptionsItemSelected (), las cuales se encargan de las funcionalidades básicas de BLE, a continuación se presenta una lista de sus funciones: OnCreate (): cada vez que se haga llamado a la actividad DeviceControlActivity.java, lo primero que realizara es entrar en el onCreate, siendo este su punto inicial.

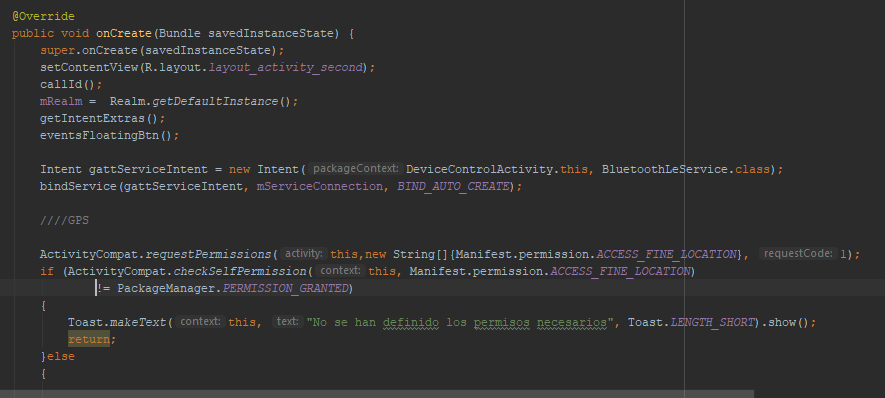
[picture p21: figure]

Los Intent en este método son utilizados con el finn de obtener información enviada desde la clase DeviceScanActivity(), donde se recibe el nombre del dispositivo y su dirección. Una vez terminadas todas las funciones del onCreate, la actividad llama al método onResume ().

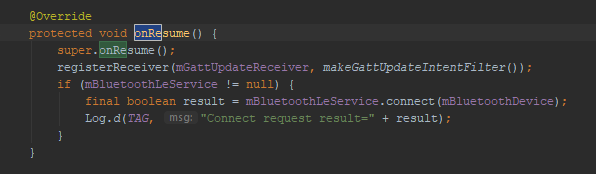
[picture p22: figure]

En este punto se crea un registerReceiver() que es leído dentro del BroadcastUpdate en el método OnReceive(), al cual se le enviara el contexto y un intent que contiene los diferentes posibles estados de la conexión. Se emplean métodos de seguridad, preguntando si existe el servicio buscado.

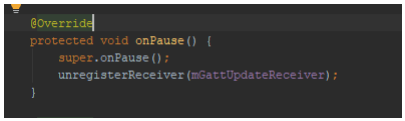
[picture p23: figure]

Cuando se cierra la aplicación por completo se hace llamado al método onDestroy() dondelo único que hace es resetear el servicio encontrado a nulo, y hacer la desconexión del servicio.

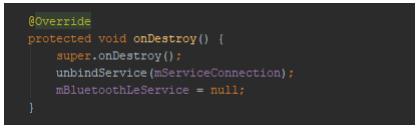
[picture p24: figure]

Para hacer una conexión con el servicio previamente creado en la clase java BluetoothLe-Service.java es necesario implementar el siguiente código.

El cual se encarga de manejar las operaciones cuando se intenta realizar una conexión al servicio, o cuando se intenta desconectar del servicio. En caso de no poder iniciar la conexión al servicio, la actividad finaliza con el comando finish().

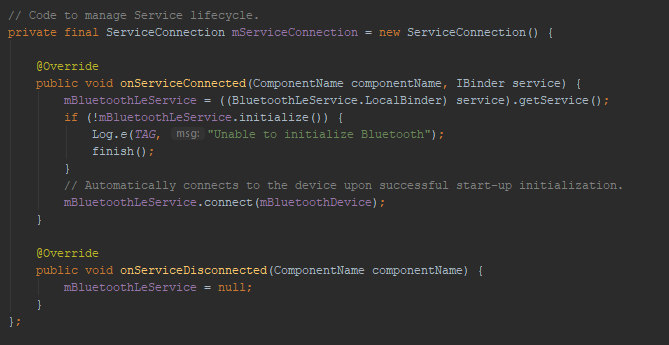
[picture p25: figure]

Por otro lado al encontrar el servicio se envía el comando connect(), si se establece la conexión. La información recibida, es el envío de paquetes de otras actividades que entran a la clase. Existen algunas condicionales que plantean medidas de seguridad para comprueban que haya llegado información. En caso de determinar que realmente hay información y no informacion basura, se procede a obtenerla y es enviada de la clase java BluetoothLEService.java.

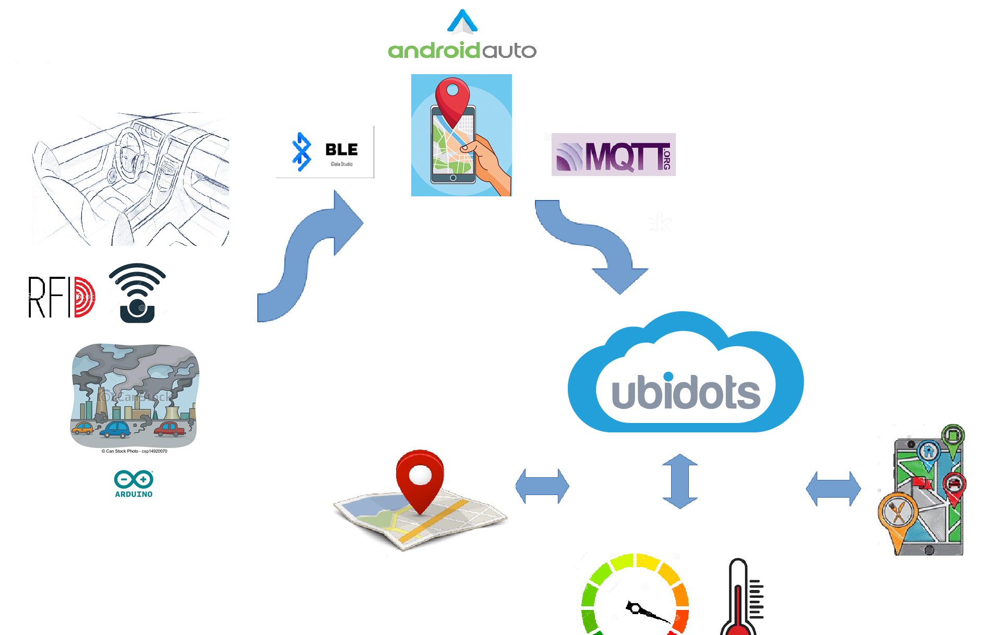
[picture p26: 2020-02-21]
Arquitectura.png

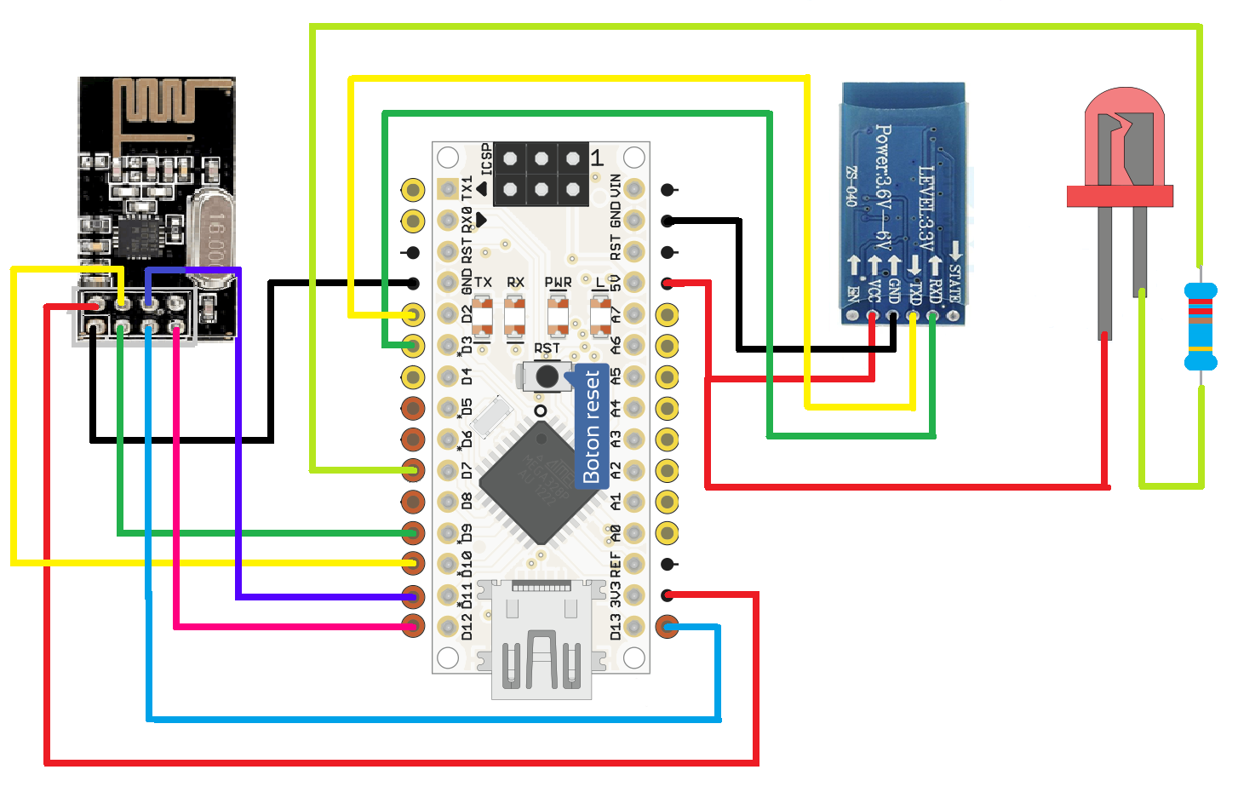
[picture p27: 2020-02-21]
ProyectoArduino/Imagenes/ConectionInternalModule.png

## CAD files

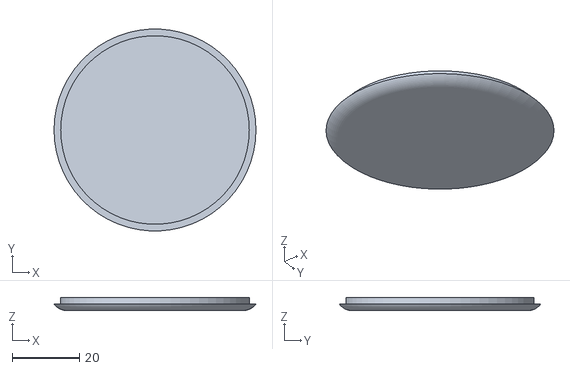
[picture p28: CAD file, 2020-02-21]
Impresion3D/UpperCover.stl
60.0 x 59.9 x 4.00

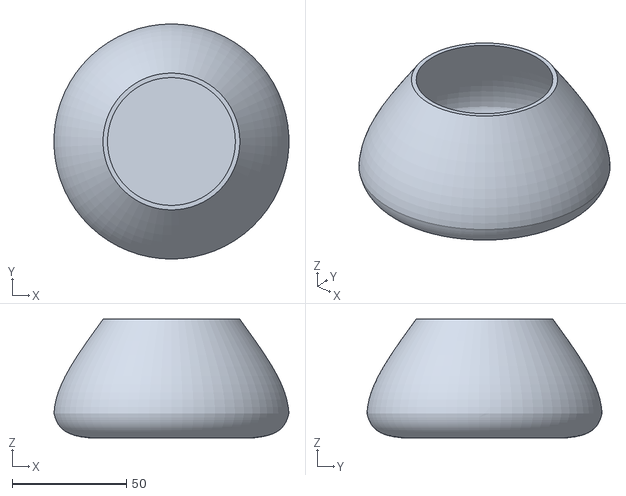
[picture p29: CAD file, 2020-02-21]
Impresion3D/Prototype.stl
103.0 x 103.1 x 52.0

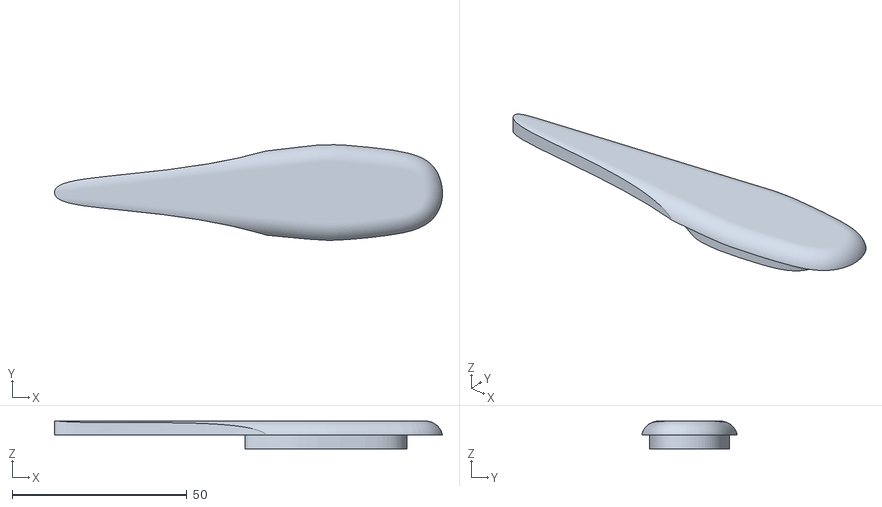
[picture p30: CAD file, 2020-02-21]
Impresion3D/SharkUpperCover.stl
111.0 x 27.4 x 8.00

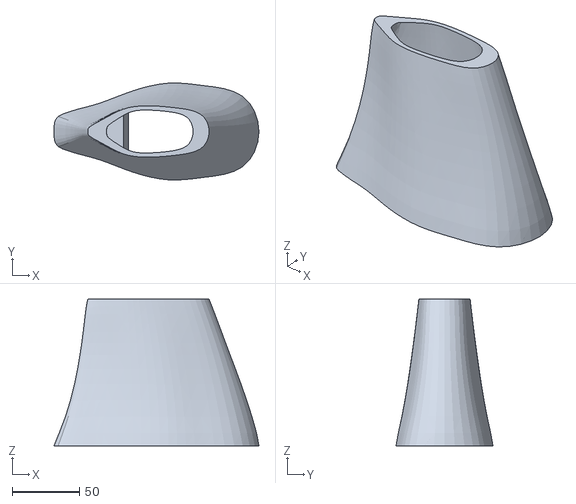
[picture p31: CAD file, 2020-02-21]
Impresion3D/SharkFinCar.stl
152.5 x 72.2 x 109.0
